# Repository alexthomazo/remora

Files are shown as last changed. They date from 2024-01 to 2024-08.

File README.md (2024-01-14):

Remora
======

Contrôleur fil pilote permettant de contrôler 7 zones et un relai.

Basé sur ESP32 et ESPHome.

Version 2.0 de Remora basé sur https://github.com/tducret/programmateur-fil-pilote-wifi/tree/master

Fonctionnalités
---------------

 * ESP32 Mini D1
 * MCP23017 pour le contrôle des 7 zones et du relai
 * Port ethernet optionnel
 * Connecteur I2C pour ecran OLED
 * Relai permettant le contrôle d'un connecteur heures pleines/creuses

Changements depuis la version 1.3
---------------------------------

 * Ajout
   - Ajout d'un condensateur 47u en entrée pour filtrage
   - Port Ethernet (optionnel)
   - Snubber RC pour maximiser la durée de vie du relai
   - LED "relai" indépendante

 * Modification
   - Base ESP32 D1 mini
   - MCP23017 en SMD pour gain de place
   - Téléinfo basée sur Denky D4 avec résistance variable et LED
   - Nouvelle ref opto fils pilotes TLP267J
   - Nouvelle ref relai G5Q-1 (mécanique moins cher SSR) 
   
 * Suppression
   - récepteurs sans fils 433 et 868Mhz
   - connecteurs SPI et Groove I2C
   - LED 3mm RGB

Les composants SMD (hors partie LAN) sont prévus pour être soudés au fer.

Schématique
-----------

Schématique

Board
-----

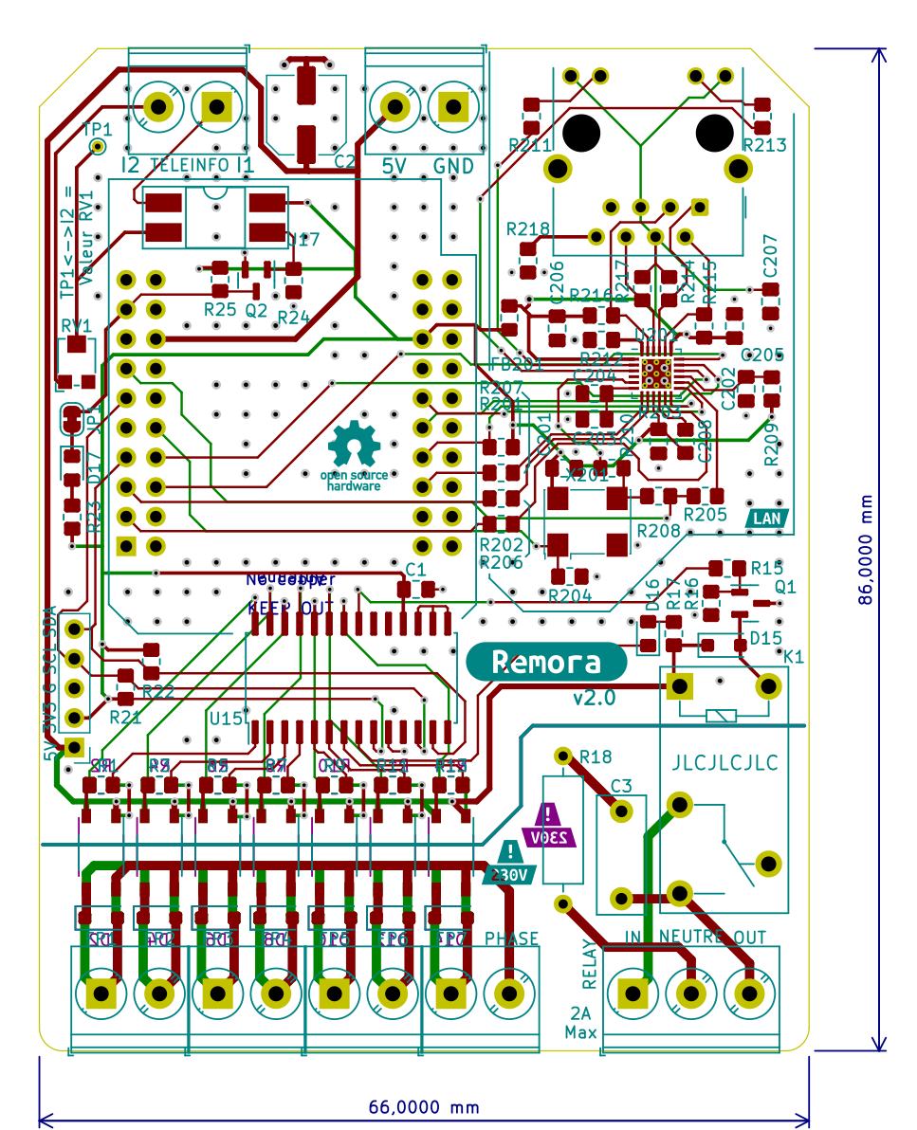
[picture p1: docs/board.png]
Board


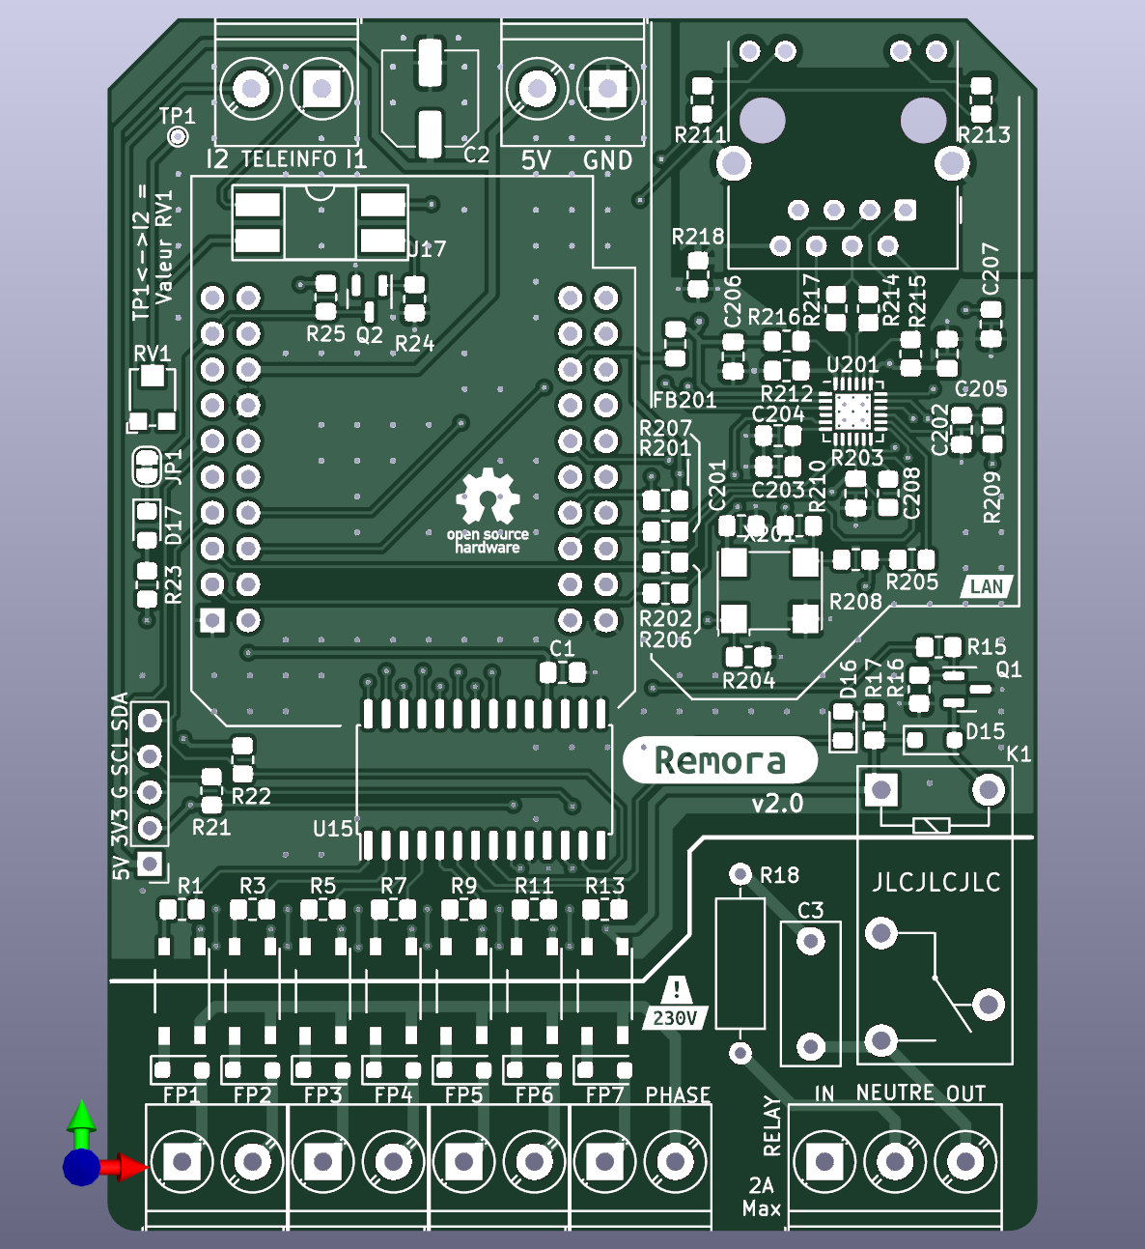
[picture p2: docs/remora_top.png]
Board top

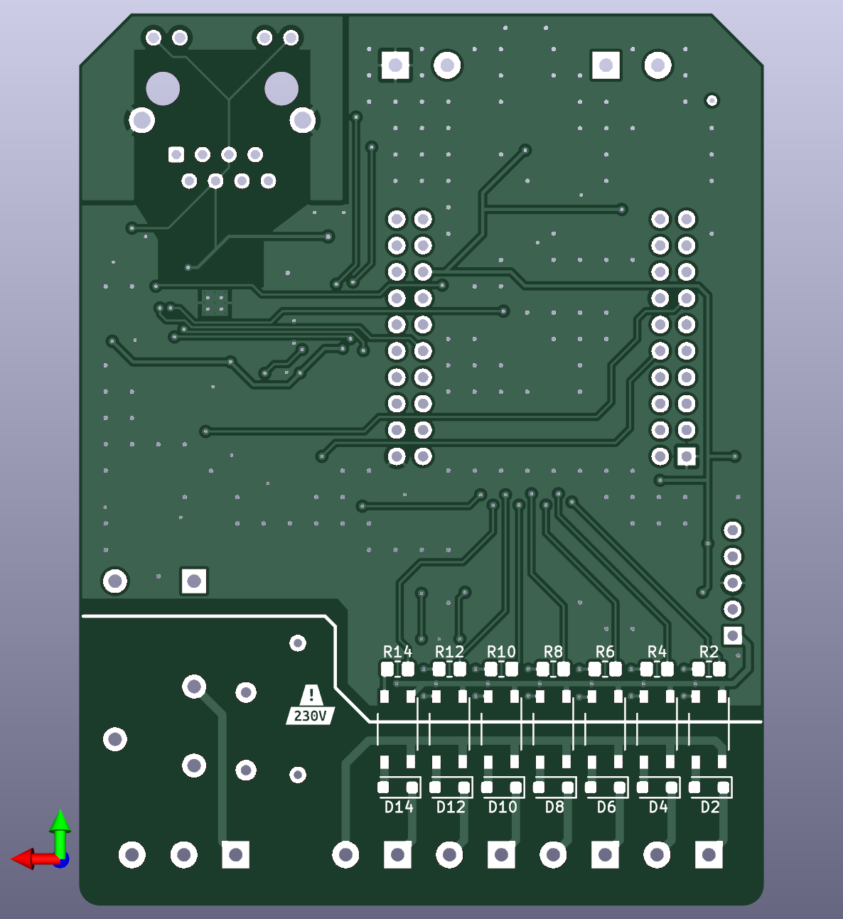
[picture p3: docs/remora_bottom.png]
Board bottom


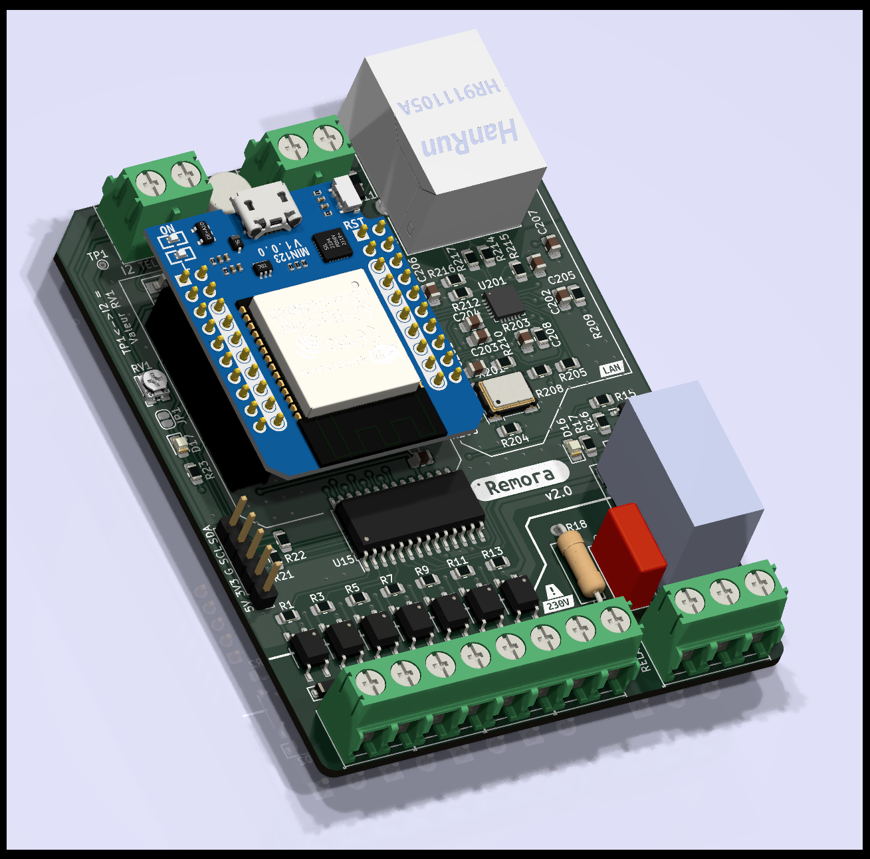
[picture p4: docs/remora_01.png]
Board 3D 01

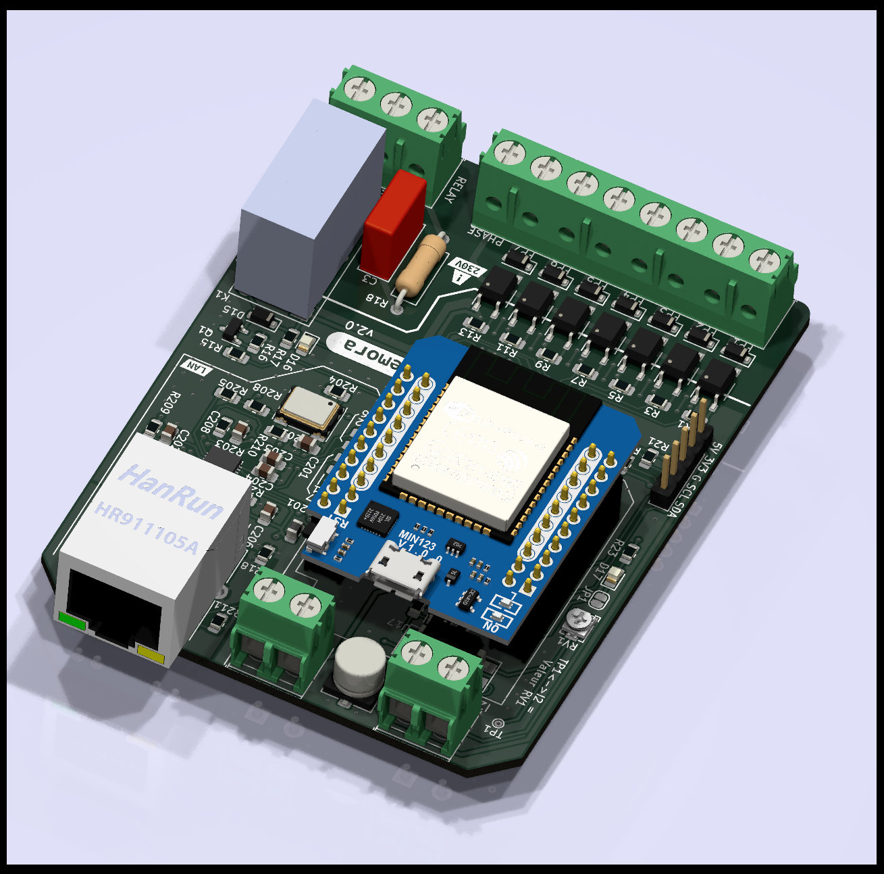
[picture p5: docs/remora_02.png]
Board 3D 02


Case
----

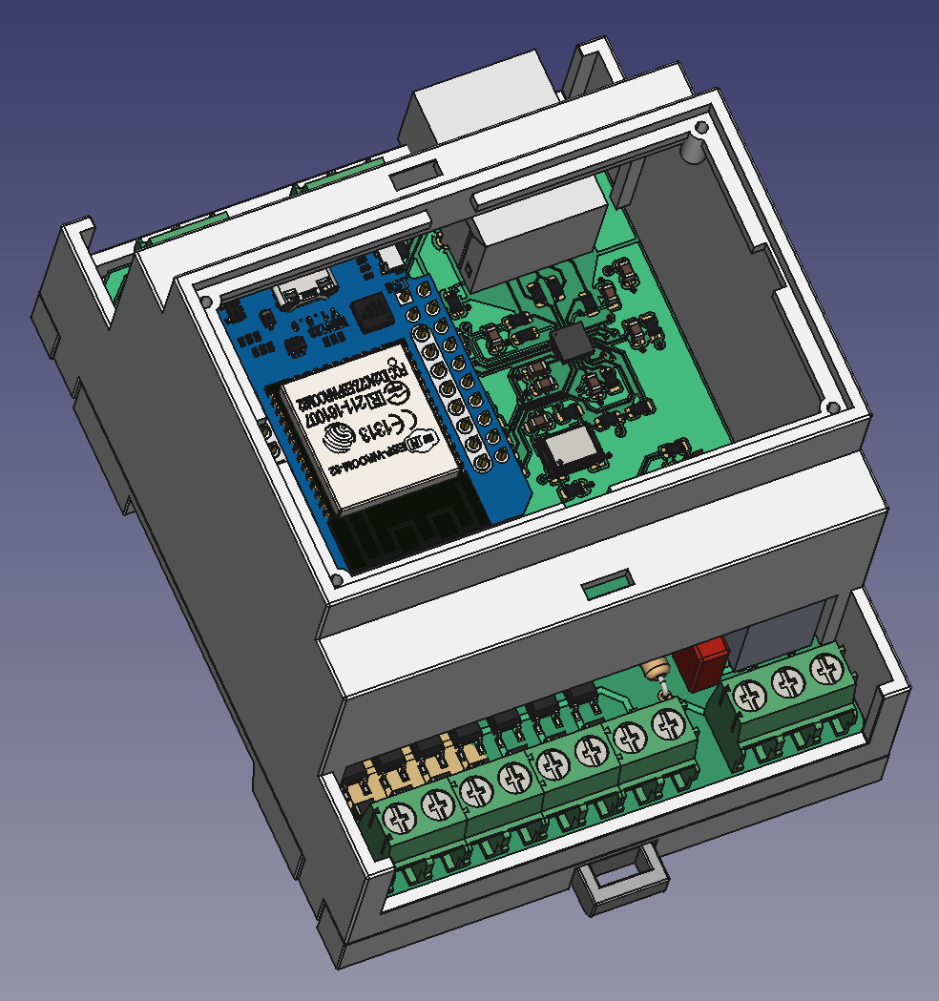
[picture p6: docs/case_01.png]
Case open

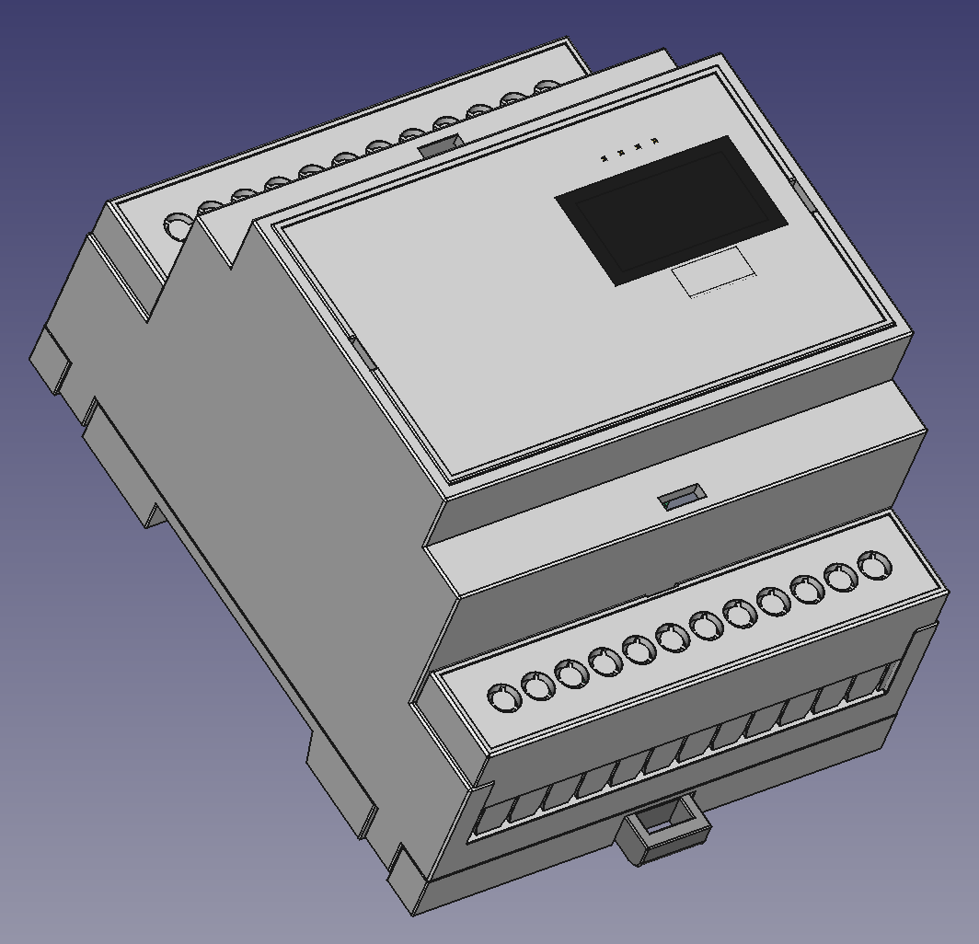
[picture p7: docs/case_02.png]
Case close with OLED


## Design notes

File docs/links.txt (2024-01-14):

Remora:
https://github.com/tducret/programmateur-fil-pilote-wifi/tree/master/Mat%C3%A9riel/1.3
https://github.com/hallard/Denky-D4

LAN:
https://www.waveshare.com/w/upload/0/08/LAN8720-ETH-Board-Schematic.pdf
https://ww1.microchip.com/downloads/en/DeviceDoc/EVB8720%20Evaluation%20Board%20Schematic.pdf
https://pcbartists.com/design/embedded/esp32-ethernet-phy-schematic-design/

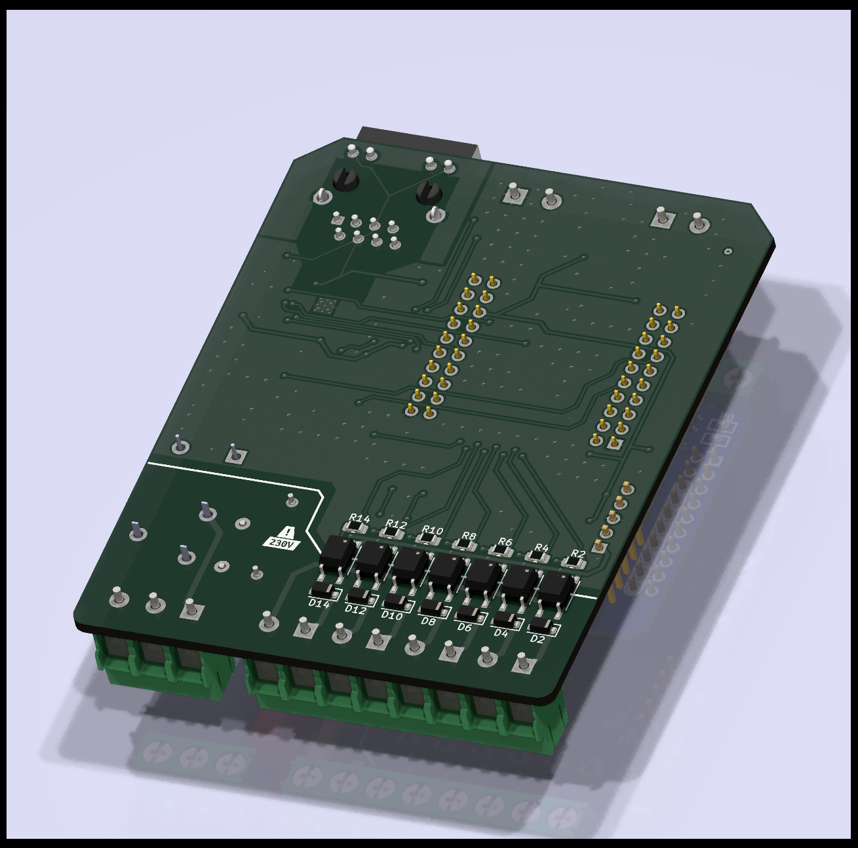
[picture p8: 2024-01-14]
docs/remora_03.png

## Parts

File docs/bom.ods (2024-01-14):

Pièce | Qte | Fabricant | Réf | P.U. | P.T.
Condo Alim | 1 |  | 47u electrolytique | 0,0326 € | 0,0326 € | https://www.mouser.fr/ProductDetail/KEMET/EDK476M035A9GAA?qs=Z46kSA%2FmtFgpOMpd%252BYN4FQ%3D%3D | https://www.lcsc.com/product-detail/Aluminum-Electrolytic-Capacitors-SMD_ROQANG-RVE1V470M0605_C131122.html
Borniers Alim | 1 |  | 2P | 0,0838 € | 0,0838 € |  | https://www.lcsc.com/product-detail/Screw-terminal_MAX-MX127-5-0-02P-GN01-Cu-Y-A_C5188440.html
MCU | 1 |  | ESP 32 Mini | 5,0000 € | 5,0000 € | https://fr.aliexpress.com/item/1005005972627549.html
Expandeur IO | 1 | Microchip | MCP23017-E/SO | 1,4386 € | 1,4386 € | https://www.mouser.fr/ProductDetail/Microchip-Technology/MCP23017-E-SO?qs=usxtMOJb1Rz8hft7vV7YMQ%3D%3D | https://www.lcsc.com/product-detail/I-O-Expanders_Microchip-Tech-MCP23017-E-SO_C47023.html
Condo Exp | 1 |  | 100 nF | 0,0043 € | 0,0043 € | https://www.mouser.fr/ProductDetail/YAGEO/CC0805KRX7R9BB104?qs=vTakOoo5QyLx0lXWgVtRhQ%3D%3D | https://www.lcsc.com/product-detail/Multilayer-Ceramic-Capacitors-MLCC-SMD-SMT_YAGEO-CC0805KRX7R9BB104_C49678.html
Resistance I2C | 2 |  | 4.7k | 0,0021 € | 0,0042 € |  | https://www.lcsc.com/product-detail/Chip-Resistor-Surface-Mount_YAGEO-RC0805FR-074K7L_C60816.html
Opto FP | 14 |  | TLP267J | 0,5218 € | 7,3052 € | https://www.mouser.fr/ProductDetail/Toshiba/TLP267JE?qs=vPP9GyyTAo3MM33pScxJbA%3D%3D | https://www.lcsc.com/product-detail/Optocouplers-Thyristor-Signal-Output_TOSHIBA-TLP267J-TPL-E-T_C393892.html
Resistance Opto | 14 |  | 680 | 0,0019 € | 0,0266 € |  | https://www.lcsc.com/product-detail/Chip-Resistor-Surface-Mount_YAGEO-RC0805FR-07680RL_C114549.html
Diode FP | 14 |  | 1N4007 | 0,0051 € | 0,0714 € | https://www.mouser.fr/ProductDetail/onsemi/NRVS1MFL?qs=%252B6g0mu59x7LVREuEHuiGKw%3D%3D | https://www.lcsc.com/product-detail/Diodes-General-Purpose_TWGMC-1N4007_C727082.html
Borniers FP | 4 |  | 2P | 0,0838 € | 0,3352 € |  | https://www.lcsc.com/product-detail/Screw-terminal_MAX-MX127-5-0-02P-GN01-Cu-Y-A_C5188440.html
Opto Tele | 1 | Lite-On | LTV-814S | 0,1049 € | 0,1049 € | https://www.mouser.fr/ProductDetail/Lite-On/LTV-814S | https://www.lcsc.com/product-detail/Optocouplers-Phototransistor-Output_Lite-On-LTV-814S-TA1_C125118.html
Resistance Opto Tele | 1 |  | Variable 0 → 2K | 0,0702 € | 0,0702 € |  | https://www.lcsc.com/product-detail/Variable-Resistors-Potentiometers_HDK-Hokuriku-Elec-Industry-VG039NCHXTB202_C128549.html
MOSFET Tele | 1 | onsemi | BSS138 | 0,0224 € | 0,0224 € | https://www.mouser.fr/ProductDetail/onsemi-Fairchild/BSS138 | https://www.lcsc.com/product-detail/MOSFETs_LGE-BSS138_C713688.html
Resistance MOSFET | 1 |  | 3K3 | 0,0024 € | 0,0024 € |  | https://www.lcsc.com/product-detail/Chip-Resistor-Surface-Mount_YAGEO-RC0805FR-073K3L_C114531.html
Resistance MOSFET | 1 |  | 10K | 0,0019 € | 0,0019 € |  | https://www.lcsc.com/product-detail/Chip-Resistor-Surface-Mount_YAGEO-RC0805JR-0710KL_C100047.html
Led Tele | 1 |  | Bleue | 0,0118 € | 0,0118 € | https://www.mouser.fr/ProductDetail/Inolux/IN-S85AT5B | https://www.lcsc.com/product-detail/Light-Emitting-Diodes-LED_Yongyu-Photoelectric-SZYY0805B_C434433.html
Resistance Led Tele | 1 |  | 470 | 0,0020 € | 0,0020 € |  | https://www.lcsc.com/product-detail/Chip-Resistor-Surface-Mount_YAGEO-RC0805FR-07470RL_C114564.html
Borniers Teleinfo | 1 |  | 2P | 0,0838 € | 0,0838 € |  | https://www.lcsc.com/product-detail/Screw-terminal_MAX-MX127-5-0-02P-GN01-Cu-Y-A_C5188440.html
Connecteur Ecran OLED | 1 |  | 1x4P | 0,0649 € | 0,0649 € |  | https://www.lcsc.com/product-detail/Female-Headers_ZHOURI-PM2-54-1-4_C5116530.html
Relai | 1 | Panasonic | ALQ105 (https://www3.panasonic.biz/ac/e_download/control/relay/power/catalog/mech_eng_lq.pdf) | 0,9281 € | 0,9281 € | https://www.mouser.fr/ProductDetail/Panasonic-Industrial-Devices/ALQ105?qs=kkkG%2F8HgOiLTrZ6QoQqhfg%3D%3D | https://www.lcsc.com/product-detail/Power-Relays_PANASONIC-ALQ105_C719517.html
Diode Relais | 1 |  | 1N4007 | 0,0051 € | 0,0051 € |  | https://www.lcsc.com/product-detail/Diodes-General-Purpose_TWGMC-1N4007_C727082.html
Transistor Relai | 1 |  | MMBT2222 | 0,0067 € | 0,0067 € |  | https://www.lcsc.com/product-detail/Bipolar-Transistors-BJT_JSMSEMI-MMBT2222A_C916372.html
Resistance Relai | 1 |  | 1k | 0,0020 € | 0,0020 € |  | https://www.lcsc.com/product-detail/Chip-Resistor-Surface-Mount_YAGEO-RC0805FR-071KL_C95781.html
Resistance Relai | 1 |  | 10k | 0,0019 € | 0,0019 € |  | https://www.lcsc.com/product-detail/Chip-Resistor-Surface-Mount_YAGEO-RC0805JR-0710KL_C100047.html
Snubber R | 1 |  | 220R / 1/2W | 0,0177 € | 0,0177 € |  | https://www.lcsc.com/product-detail/Through-Hole-Resistors_CCO-Chian-Chia-Elec-MF1-2W-220-1-T_C119410.html
Snubber C | 1 |  | 0.1uF / 600V | 0,0572 € | 0,0572 € | https://www.mouser.fr/ProductDetail/Panasonic/ECW-FD2J104K4?qs=7EBvPakHacU48DCioWGmwQ%3D%3D | https://www.lcsc.com/product-detail/Polypropylene-Film-Capacitors-CBB_SRD-Shenzhen-Sincerity-Tech-MPP104J2J1006115LC_C2895620.html
Borniers relai | 1 |  | 3P | 0,0743 € | 0,0743 € |  | https://www.lcsc.com/product-detail/Screw-terminal_MAX-MX127-5-0-03P-GN01-Cu-Y-A_C5188441.html
LED Relai | 1 |  | Rouge | 0,0086 € | 0,0086 € | https://www.mouser.fr/ProductDetail/Inolux/IN-S85AT5UW | https://www.lcsc.com/product-detail/Light-Emitting-Diodes-LED_XINGLIGHT-XL-2012VRC_C7371913.html
Ecran OLED I2C | Opt |  | SSD1306 |  |  | https://fr.aliexpress.com/item/1005004495098319.html

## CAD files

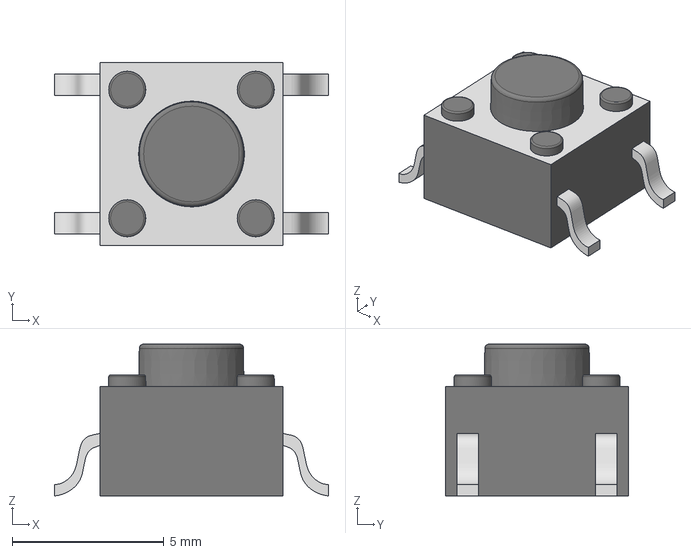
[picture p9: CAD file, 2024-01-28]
3d/Tactal Switch - SMD (6mm x 6mm x 5mm).stp
9.02 x 6.03 x 5.00 mm

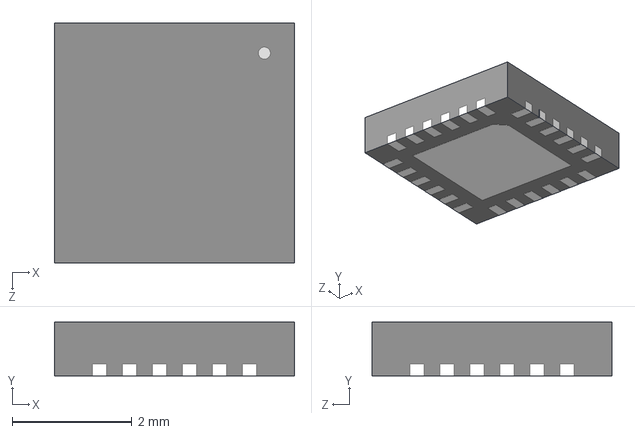
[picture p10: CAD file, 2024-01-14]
3d/QFN 24 4x4.step
4.00 x 0.9 x 4.00 mm

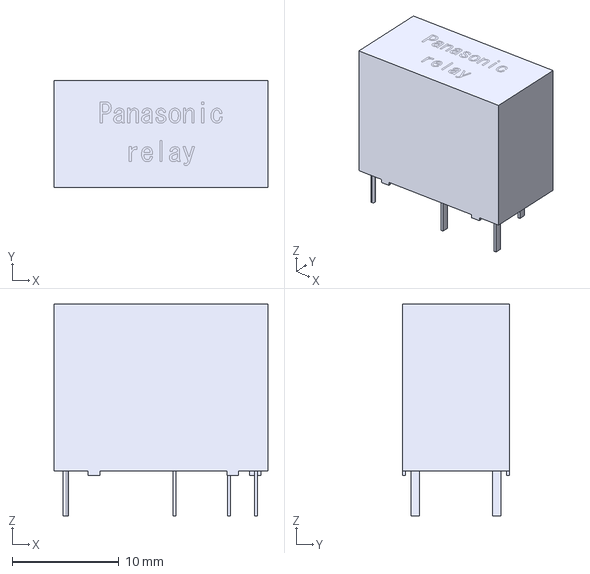
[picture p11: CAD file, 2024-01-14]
3d/alq1.step
20.0 x 10.0 x 19.8 mm

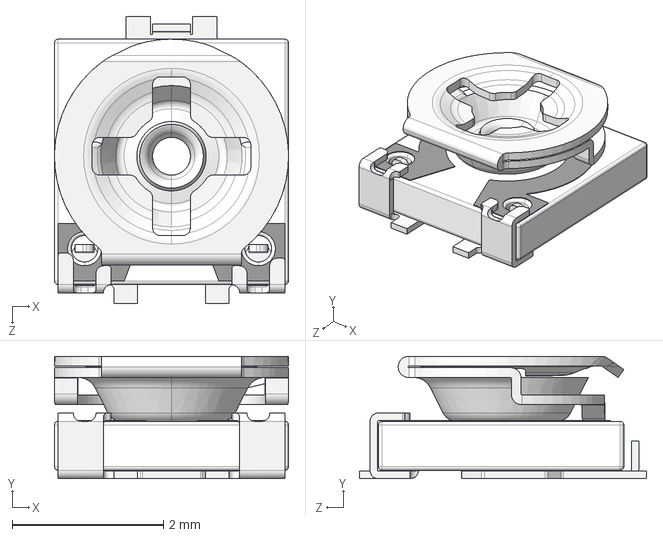
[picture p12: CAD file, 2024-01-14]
3d/EVM3ESX50Bxx-Panasonic.STEP
3.10 x 1.62 x 3.80 mm

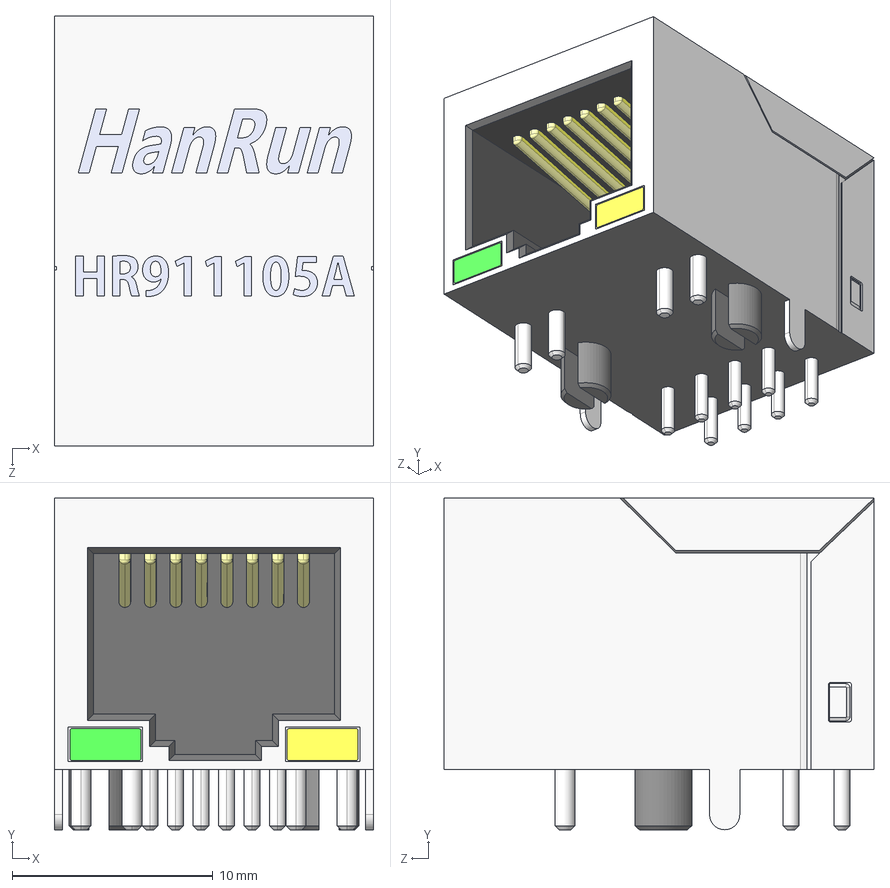
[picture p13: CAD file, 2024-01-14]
3d/HR911105A.STEP
15.9 x 16.5 x 21.4 mm

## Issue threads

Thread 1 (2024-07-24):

TELEINFO PIN

baramuse, 2024-07-24:
Hi,

I've got a question conerning the pinout: if I undestrand correctly, the TELEINFO info pin is mapped to SD1/GPIO8 on ESP32 ?
If so, is that correct as the ESP32 doc states the SD1 is reserved :
`This pin cannot be used on ESP32s and is already used by the flash interface (function: Flash Data 1).`

Any clue ?

alexandre-thomazo-idnow, 2024-07-24:
Hello,

Yes, I just test it last week and realized the issue, I pushed a new version with the pin routed to GPIO13 and made a hardware patch with a strap wire. It's working with this pin :)

alexthomazo, 2024-07-24:
Hello,

Yes, I just test it last week and realized the issue, I pushed a new version with the pin routed to GPIO13 and made a hardware patch with a strap wire. It's working with this pin :)

baramuse, 2024-07-24:
damned I've printed a few pcb already :')

baramuse, 2024-07-24:
> Hello,
>
> Yes, I just test it last week and realized the issue, I pushed a new version with the pin routed to GPIO13 and made a hardware patch with a strap wire. It's working with this pin :)

could you share a picture of your hardware patch ?

alexthomazo, 2024-07-24:
Erf, I don't have a picture right now but the hardware patch is not to complicated. I cut the trace that going left of the R25 resistor with a cutter.
Then I take a strap wire, solder on the bottom pad of the resistor the routing it on the bottom layer going right of the power pin then solder it to the ESP32 pin of the GPIO13.

Here's a quick draw on the PCB of the wire
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

baramuse, 2024-07-24:
Alright !
Do you think I could do the hardware patch on the wemo instead ?
Cut the trace of the GPIO8 -> ESP and strap wire GPIO8->GPIO13 ?
I'd rather mess a 4$ board that the remora2 ^^

alexthomazo, 2024-07-24:
Yes I can think so, you cut the trace just after the pad and redirect with a wire at the other pin like that
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

baramuse, 2024-07-25:
Well I did the hardware patch.
Tested the continuity bewteen GPIO8 and GPIO16 (green wire on your schematics) and the non-continuity between GPIO8 and the 3rd vertical pad on the CPU (SD1) but when powerd, nothing get to the TELEINFO.
The blue led is not blinking. It actually WAS blinking before the hardware patch - but then I guess just because SD1 was live..)
Any idea how to "debug" that ?

By the way, are you programming with ESPHome ?

Cheers

alexthomazo, 2024-07-25:
That's weird, for me as soon as I put the the teleinfo on the right pin, it was working right away. However I cut the trace for the led before (it was also blinking when connected to SD1, I supposed at the moment that it was triggered because the teleinfo was not connected at all).
I don't really know how to debug, I use ESPHome indeed, I was planning to upload an configuration example in the following days but I can push it right know if you want to check with yours.

alexthomazo, 2024-07-25:
I push my [ESPHome configuration](https://github.com/alexthomazo/remora/blob/main/esphome/esphome.yaml), I'm in standard mode however.

Maybe it came from the uart configuration, because the ESP32 has 2 uart (that's why it's id uart_1 if I remember correctly).

baramuse, 2024-07-25:
Yep, same thing but I called it `uart_bus` instead of `uart_1` in your case but samed same.

baramuse, 2024-07-25:
Well.. I thought I misolder the opto, but I tried twice and still nothing and I don't know how to "debug" :(

alexthomazo, 2024-07-25:
ok, I think you don't have a logic analyzer or an oscilloscope to check if you have a signal a the output of the optocoupler or the mosfet ^^ ?

baramuse, 2024-07-25:
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

baramuse, 2024-07-25:
sadly not yet, but I'll end up buying one I guess

baramuse, 2024-07-25:
humm I do have continuity between I1 -> TI1 (on the opto) but not from I2 -> TI2R
I do have continuity between I1 -> TP1 though... what's the RV1 thingy ?

alexthomazo, 2024-07-25:
That's so cool to see the project build by someone else :grin:

RV1 is a variable resistor to adjust the signal coming from the counter, if you don't already play with check, try to turn to see if it's better or not.

baramuse, 2024-07-25:
turning it left gives me continuity I2 -> TI2R.
should I tune it to a more specific value ?
still no teleinfo though.

alexthomazo, 2024-07-25:
I'm not an expert on that topic, maybe asking in the Remora forum to have more users with knowledge of the historique mode of the teleinfo ?

baramuse, 2024-07-25:
I don't think historical or standard have an impact on my issue here :)
RV1 is a variable resistor then ? it means I need to set it to a particular value ?

reading charle's blog, especially on "choix des resistances" I feel i need to get it to around 4.7k
also in his designs he puts a 4,7K on I2 ? https://github.com/hallard/teleinfo/tree/master/MicroTeleinfo

baramuse, 2024-07-25:
Turning it all the way to the right gives me a 2.14K, is it the highest value ?

alexthomazo, 2024-07-25:
> Turning it all the way to the right gives me a 2.14K, is it the highest value ?

Yes, it's a 2K variable resistor, I take the specs from the Denky D4 for that part https://github.com/hallard/Denky-D4

baramuse, 2024-07-25:
yep, makes sense... well I don't know what's wrong with my teleinfo then :(
so close yet so far !

alexthomazo, 2024-07-25:
it was working before with the same cable on the old remora ?

baramuse, 2024-07-25:
not a remora but a wemosD1 with a shield (and still works when I plug it back in)

baramuse, 2024-07-25:
I should see the blue led blink whenever I have any teleinfo right ? (ruling out the software component)

alexthomazo, 2024-07-25:
Yes, the led is connected to the mosfet so it should blink without any software

baramuse, 2024-07-25:
ok something must be wrong with my opto (the only component that did not come soldered ^^) because I got no blue led when only powered (no ESP32).
I tried swaping the teleinfo wires, etc, nothing... so must be my opto

alexthomazo, 2024-07-25:
> ok something must be wrong with my opto (the only component that did not come soldered ^^) because I got no blue led when only powered (no ESP32). I tried swaping the teleinfo wires, etc, nothing... so must be my opto

You need to at least have the ESP32 plugged in because it's provide the 3.3V required for the opto, if you want to test without nothing, link at least the 3.3V of the ESP to the board with jump wires.

baramuse, 2024-07-25:
Alright I tried again, plugged the old Wemos nd worked, so must be something with the opto (I recycled it from another pitinfo...)
I'll order the wright ones and try again !
Thanks for the support !

baramuse, 2024-10-09:
> ![image](https://private-user-images.githubusercontent.com/1180901/352177930-d5ff3795-6b68-4608-a7d7-b4667a161c73.jpeg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) ![image](https://private-user-images.githubusercontent.com/1180901/352178087-fe93ba37-66a8-4edb-9809-cf10a06de4cf.jpeg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)
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
baramuse, 2024-10-12:
Thanks !
Just ordered them..
I'll try the hw hack for the relay later.
So that's the second hw update with the reassign of GPIO13 right ?
Also, can't the snubber be implemented on the board as well ?
And in your changelog you actually already said `Snubber RC pour maximiser la durée de vie du relai` ?

How hard would it e to replace the ETHERNET circuitery with a 220V/5V transformer ?
As you already have a 220V input (and output if you use the relay) that would remove the need of another device to get the 5volts

Also, you already have the PHASE input for the FPs, couldn't you merge it with the IN of the relay in order to only tu plug one in ? (they maybe are stupid questions, I'm not electronician, but more a cable hunter ^^)

alexthomazo, 2024-10-12:
> So that's the second hw update with the reassign of GPIO13 right ?

Yes, and also the last one, I have the board running with these two updates for several weeks now and it's working well.

> Also, can't the snubber be implemented on the board as well ? And in your changelog you actually already said `Snubber RC pour maximiser la durée de vie du relai` ?

I didn't included the snubber directly with the relay on the PCB traces so you can use the relay for other thing if you want (like controlling a light), the snubber is only needed because the small relay of the PCB is going to drive the bigger relay of the hotwater. The drawback is that you must to do the connection at the outside.

> How hard would it e to replace the ETHERNET circuitery with a 220V/5V transformer ? As you already have a 220V input (and output if you use the relay) that would remove the need of another device to get the 5volts And maybe lower the overall price if no ethernet is needed

I also thought about it, but first I wanted to have Ethernet, and secondly, I'm not a 100% confident with 220V current, so I kept the remora original design that kept all the high current at the bottom of the PCB. However it will be completely doable to rework the right part, removing the Ethernet then put a integrated transformer.

> Also, you already have the `PHASE` input for the `FPx`, couldn't you merge it with the `IN` of the relay in order to only tu plug one in ?

For the same reason of not including the snubber directly, I did not include the `PHASE` with the relay so you can use it to do whatever you want (and also drive something from another circuit breaker).

> (they maybe are stupid questions, I'm not electronician, but more a cable hunter ^^)

Not stupid at all, as you can see I think about that and made some choices, it's cool to see someone interested with the project and trying to understand :)

alexandre-thomazo-idnow, 2024-10-28:
> it looks on my printed board, I already had that fix, right ?

Oh yes, you should had made the PCB printed after I made the fix, good for you

> Also I plan to put that RC snubber in parrallel is that right ?

Yes, it's the right thing :)

baramuse, 2024-10-30:
Alright !
It starts working !

I've set it up with my HA installation and it starts talking with the heaters !!

Have you tested all the modes ?
On my side, at least for now, the heater "understands" correcly the "off" and "hors-gel" instructions. (both "half signals")
It seems unresponsive to "eco" and "confort" (both "full signals")

Not sure how can I test what's wrong.
I've bought a handeled oscilloscope (BSIDE ZT-702S) but I'm not sure I understand what I'm seeing...

Any clues ?

Cheers

alexthomazo, 2024-10-31:
Hello, yes, all the modes are working on my side.

That's odd that you have only "half" signal working, because in order to have "full" signal, it's just a combinaison of the 2 "half" signal.

Are you sure that the configuration in HA is OK ? You need to activate 2 pins on the MCP to have the "full" signal.

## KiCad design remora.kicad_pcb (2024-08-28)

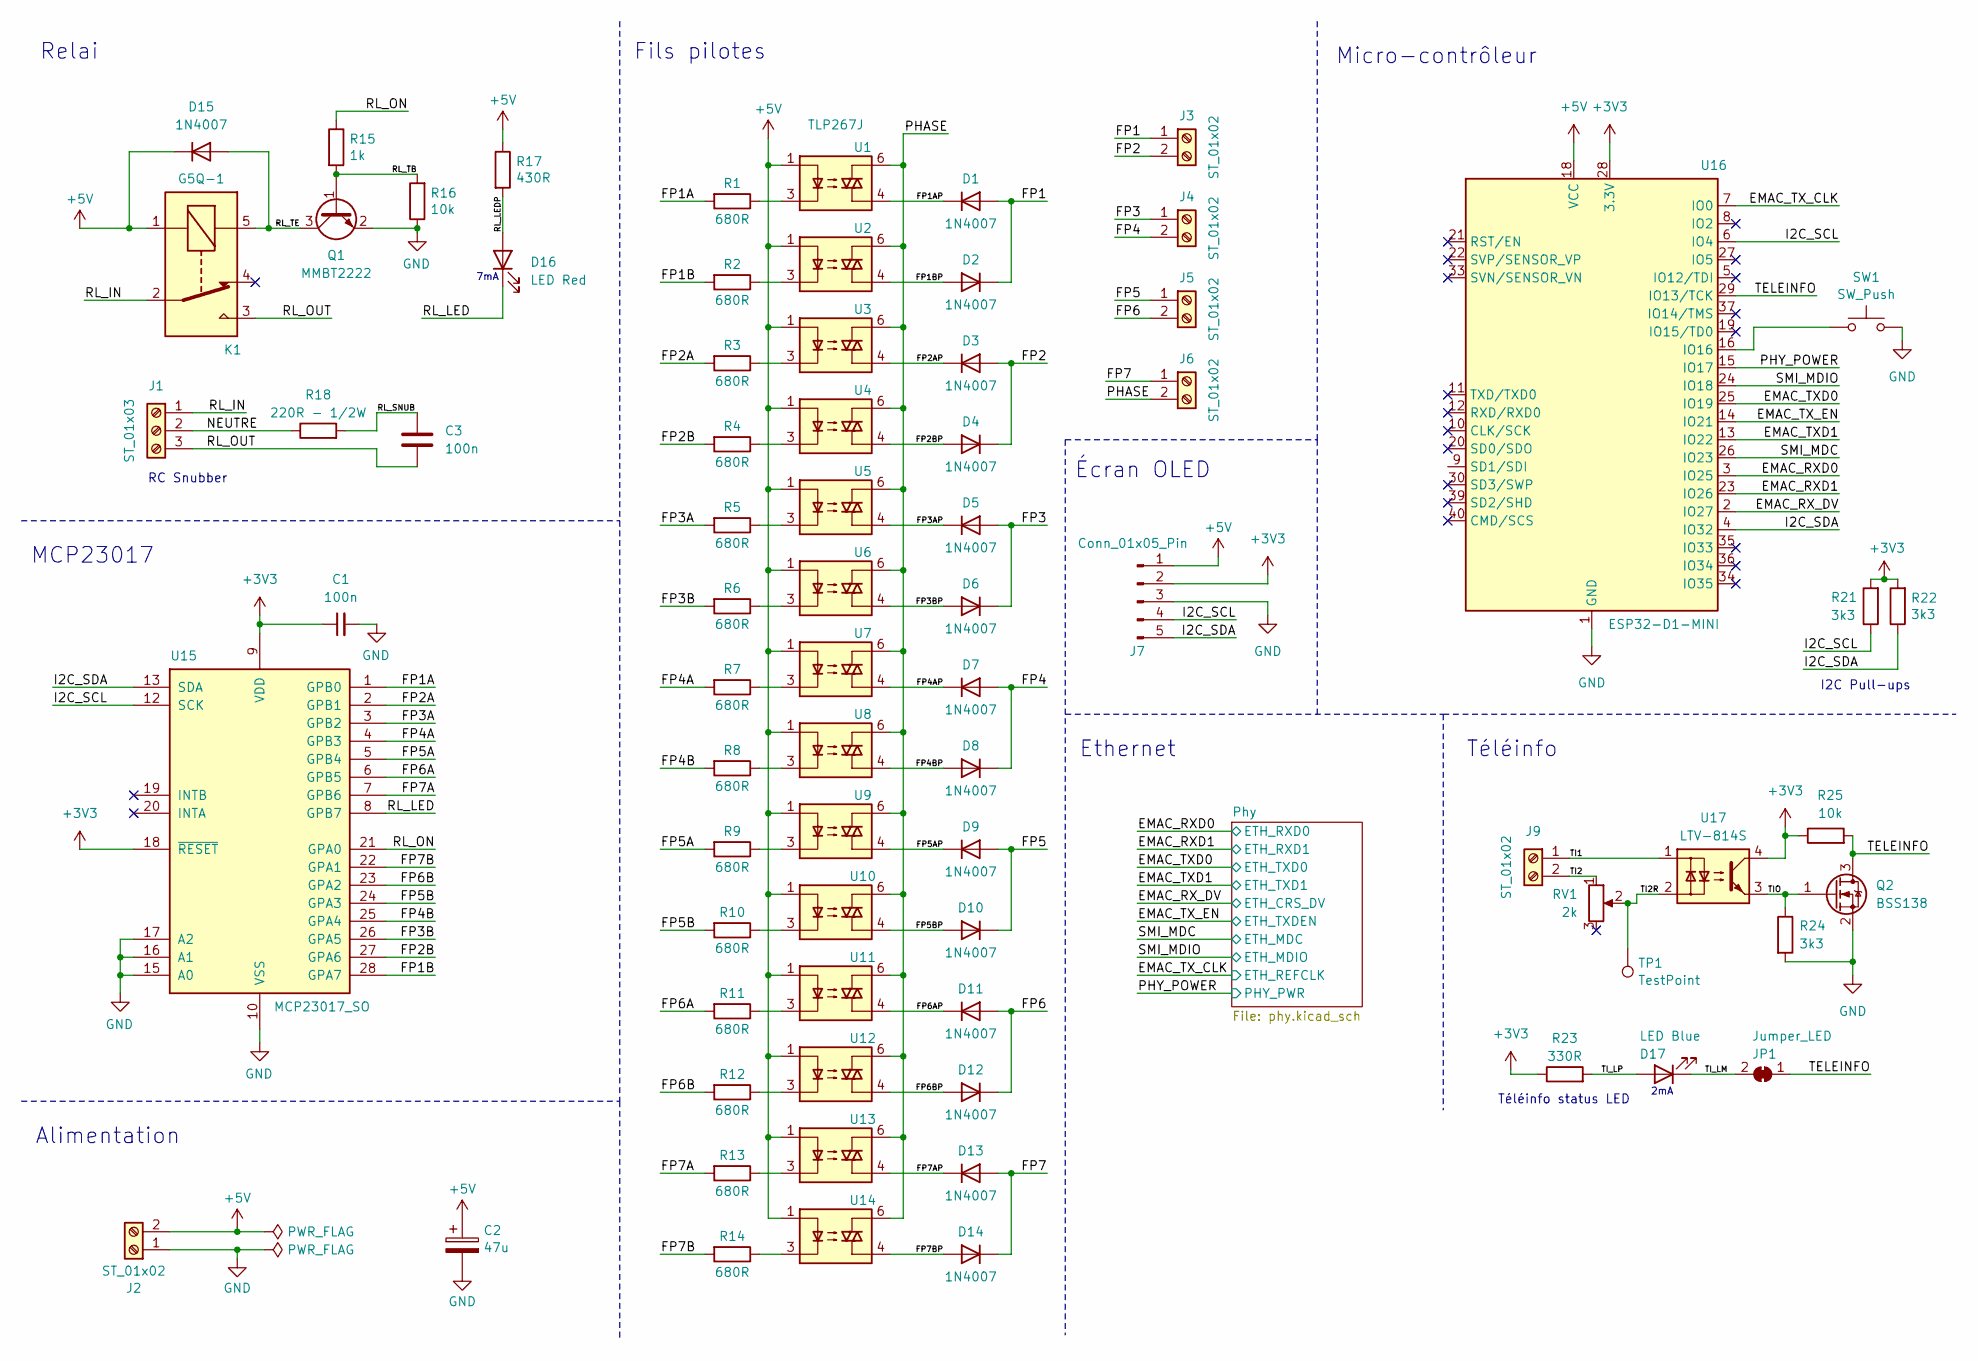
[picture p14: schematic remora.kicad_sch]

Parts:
C1: 100n; C_0805_2012Metric_Pad1.18x1.45mm_HandSolder; Mouser# 603-CC805KRX7R9BB104; LCSC# C49678
C2: 47u; C_Elec_6.3x5.4; Mouser# 80-EDK476M035A9GAA; LCSC# C131122
C3: 100n; C_Rect_L11.5mm_W5.6mm_P10.00mm_MKT; LCSC# C506867
D1, D2, D3, D4, D5, D6, D7, D8, D9, D10, D11, D12, D13, D14, D15: 1N4007; D_SOD-123FL; Mouser# 863-NRVS1MFL; LCSC# C727082
D16: LED Red; LED_0805_2012Metric_Pad1.15x1.40mm_HandSolder; Mouser# 743-IN-S85AT5UW; LCSC# C7371913
D17: LED Blue; LED_0805_2012Metric_Pad1.15x1.40mm_HandSolder; Mouser# 743-IN-S85AT5B; LCSC# C434433
J1: ST_01x03; TerminalBlock_Phoenix_PT-1,5-3-5.0-H_1x03_P5.00mm_Horizontal; Mouser# 490-TB003-500-P03BE; LCSC# C5188464
J2, J3, J4, J5, J6, J9: ST_01x02; TerminalBlock_Phoenix_PT-1,5-2-5.0-H_1x02_P5.00mm_Horizontal; Mouser# 490-TB003-500-P02BE; LCSC# C5188463
J7: Conn_01x05_Pin; PinHeader_1x05_P2.54mm_Vertical; Mouser# 200-EW0509TS300; LCSC# C492404
JP1: Jumper_LED; SolderJumper-2_P1.3mm_Bridged_RoundedPad1.0x1.5mm
K1: G5Q-1; Relay_SPDT_Omron-G5Q-1; Mouser# 769-ALQ105; LCSC# C719517
Q1: MMBT2222; SOT-23; Mouser# 771-MMBT2222A215; LCSC# C916372
Q2: BSS138; SOT-23; Mouser# 771-BSS138P215; LCSC# C713688
R1, R2, R3, R4, R5, R6, R7, R8, R9, R10, R11, R12, R13, R14: 680R; R_0805_2012Metric_Pad1.20x1.40mm_HandSolder; Mouser# 603-RC0805FR-07680RL; LCSC# C114549
R15: 1k; R_0805_2012Metric_Pad1.20x1.40mm_HandSolder; Mouser# 603-RC0805FR-071KL
R16, R25: 10k; R_0805_2012Metric_Pad1.20x1.40mm_HandSolder; Mouser# 603-RC0805FR-0710KL
R17: 430R; R_0805_2012Metric_Pad1.20x1.40mm_HandSolder; Mouser# 603-RC0805FR-07430RL
R18: 220R - 1/2W; R_Axial_DIN0309_L9.0mm_D3.2mm_P12.70mm_Horizontal; Mouser# 603-CFR-50JR-52-220R; LCSC# C119410
R21, R22, R24: 3k3; R_0805_2012Metric_Pad1.20x1.40mm_HandSolder; Mouser# 603-RC0805FR-073K3L
R23: 330R; R_0805_2012Metric_Pad1.20x1.40mm_HandSolder; Mouser# 603-RC0805FR-07330RL; LCSC# C105878
RV1: 2k; Potentiometer_Bourns_TC33X_Vertical; Mouser# 652-TC33X-2-202E; LCSC# C128549
SW1: SW_Push; SW_Push_1P1T_NO_6x6mm_H9.5mm; Mouser# 179-TS046655BK160SMT; LCSC# C255812
TP1: TestPoint; TestPoint_THTPad_D1.0mm_Drill0.5mm
U1, U2, U3, U4, U5, U6, U7, U8, U9, U10, U11, U12, U13, U14: TLP267J; MFSOP6-4_4.4x3.6mm_P1.27mm; Mouser# 757-TLP267JE; LCSC# C393892
U15: MCP23017_SO; SOIC-28W_7.5x17.9mm_P1.27mm; Mouser# 579-MCP23017-E/SO; LCSC# C629440
U16: ESP32-D1-MINI
U17: LTV-814S; DIP-4_W8.89mm_SMDSocket_LongPads; Mouser# 859-LTV-814S; LCSC# C125118

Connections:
+3V3: C1.1, J7.2, R21.2, R22.2, R23.1, R25.1, U15.9 (VDD), U15.18 (~RESET), U16.28 (3.3V), U17.4; also elsewhere on the board
+5V: C2.1, D15.1 (K), J2.2, J7.1, K1.1, R17.1, U1.1, U2.1, U3.1, U4.1, U5.1, U6.1, U7.1, U8.1, U9.1, U10.1, U11.1, U12.1, U13.1, U14.1, U16.18 (VCC)
/EMAC_RXD0: U16.3 (IO25); also elsewhere on the board
/EMAC_RXD1: U16.23 (IO26); also elsewhere on the board
/EMAC_RX_DV: U16.2 (IO27); also elsewhere on the board
/EMAC_TXD0: U16.25 (IO19); also elsewhere on the board
/EMAC_TXD1: U16.13 (IO22); also elsewhere on the board
/EMAC_TX_CLK: U16.7 (IO0); also elsewhere on the board
/EMAC_TX_EN: U16.14 (IO21); also elsewhere on the board
/FP1: D1.2 (A), D2.1 (K), J3.1
/FP1A: R1.2, U15.1 (GPB0)
/FP1AP: D1.1 (K), U1.4
/FP1B: R2.2, U15.28 (GPA7)
/FP1BP: D2.2 (A), U2.4
/FP2: D3.2 (A), D4.1 (K), J3.2
/FP2A: R3.2, U15.2 (GPB1)
/FP2AP: D3.1 (K), U3.4
/FP2B: R4.2, U15.27 (GPA6)
/FP2BP: D4.2 (A), U4.4
/FP3: D5.2 (A), D6.1 (K), J4.1
/FP3A: R5.2, U15.3 (GPB2)
/FP3AP: D5.1 (K), U5.4
/FP3B: R6.2, U15.26 (GPA5)
/FP3BP: D6.2 (A), U6.4
/FP4: D7.2 (A), D8.1 (K), J4.2
/FP4A: R7.2, U15.4 (GPB3)
/FP4AP: D7.1 (K), U7.4
/FP4B: R8.2, U15.25 (GPA4)
/FP4BP: D8.2 (A), U8.4
/FP5: D9.2 (A), D10.1 (K), J5.1
/FP5A: R9.2, U15.5 (GPB4)
/FP5AP: D9.1 (K), U9.4
/FP5B: R10.2, U15.24 (GPA3)
/FP5BP: D10.2 (A), U10.4
/FP6: D11.2 (A), D12.1 (K), J5.2
/FP6A: R11.2, U15.6 (GPB5)
/FP6AP: D11.1 (K), U11.4
/FP6B: R12.2, U15.23 (GPA2)
/FP6BP: D12.2 (A), U12.4
/FP7: D13.2 (A), D14.1 (K), J6.1
/FP7A: R13.2, U15.7 (GPB6)
/FP7AP: D13.1 (K), U13.4
/FP7B: R14.2, U15.22 (GPA1)
/FP7BP: D14.2 (A), U14.4
/I2C_SCL: J7.4, R21.1, U15.12 (SCK), U16.6 (IO4)
/I2C_SDA: J7.5, R22.1, U15.13 (SDA), U16.4 (IO32)
/NEUTRE: J1.2, R18.1
/PHASE: J6.2, U1.6, U2.6, U3.6, U4.6, U5.6, U6.6, U7.6, U8.6, U9.6, U10.6, U11.6, U12.6, U13.6, U14.6
/PHY_POWER: U16.15 (IO17); also elsewhere on the board
/RL_IN: J1.1, K1.2
/RL_LED: D16.1 (K), U15.8 (GPB7)
/RL_LEDP: D16.2 (A), R17.2
/RL_ON: R15.1, U15.21 (GPA0)
/RL_OUT: C3.1, J1.3, K1.3
/RL_SNUB: C3.2, R18.2
/RL_TB: Q1.1 (B), R15.2, R16.2
/RL_TE: D15.2 (A), K1.5, Q1.3 (C)
/SMI_MDC: U16.26 (IO23); also elsewhere on the board
/SMI_MDIO: U16.24 (IO18); also elsewhere on the board
/TELEINFO: JP1.1 (A), Q2.3 (D), R25.2, U16.29 (IO13/TCK)
/TI1: J9.1, U17.1
/TI2: J9.2, RV1.1
/TI2R: RV1.2, TP1.1, U17.2
/TIO: Q2.1 (G), R24.1, U17.3
/TI_LM: D17.1 (K), JP1.2 (B)
/TI_LP: D17.2 (A), R23.2
GND: C1.2, C2.2, J2.1, J7.3, Q1.2 (E), Q2.2 (S), R16.1, R24.2, SW1.2, U15.10 (VSS), U15.15 (A0), U15.16 (A1), U15.17 (A2), U16.1 (GND), U16.17 (GND), U16.31 (GND); also elsewhere on the board
unnamed: R1.1, U1.3
unnamed: R2.1, U2.3
unnamed: R3.1, U3.3
unnamed: R4.1, U4.3
unnamed: R5.1, U5.3
unnamed: R6.1, U6.3
unnamed: R7.1, U7.3
unnamed: R8.1, U8.3
unnamed: R9.1, U9.3
unnamed: R10.1, U10.3
unnamed: R11.1, U11.3
unnamed: R12.1, U12.3
unnamed: R13.1, U13.3
unnamed: R14.1, U14.3
unnamed: SW1.1, U16.16 (IO16)

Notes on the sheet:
7mA
MCP23017
Relai
2mA
Écran OLED
Fils pilotes
Alimentation
RC Snubber
Téléinfo
I2C Pull-ups
Ethernet
Téléinfo status LED
Micro-contrôleur

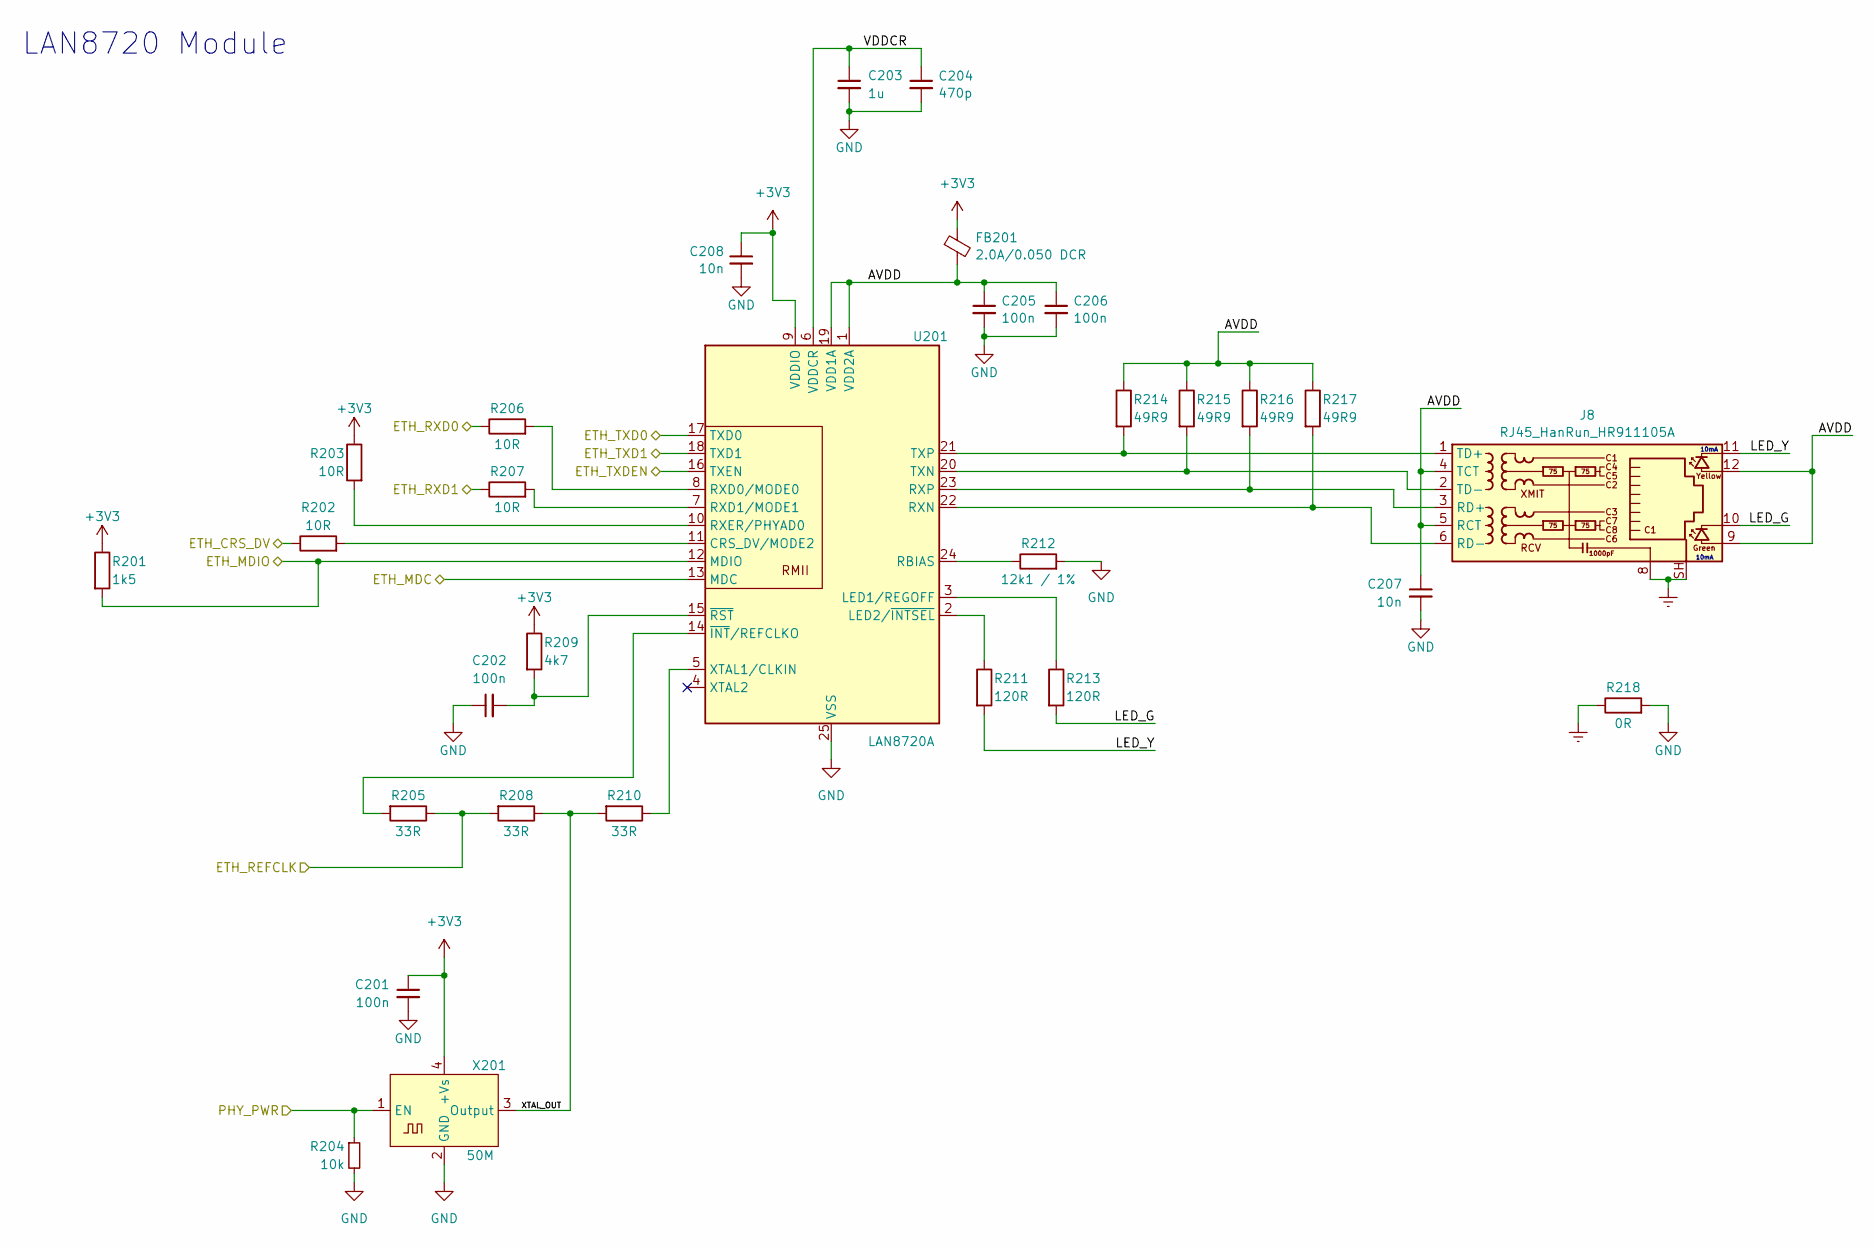
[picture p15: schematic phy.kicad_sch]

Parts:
C201, C202, C205, C206: 100n; C_0805_2012Metric_Pad1.18x1.45mm_HandSolder; Mouser# 603-CC805KRX7R9BB104; LCSC# C49678
C203: 1u; C_0805_2012Metric_Pad1.18x1.45mm_HandSolder; Mouser# 603-CC805KKX7R9BB105; LCSC# C91185
C204: 470p; C_0805_2012Metric_Pad1.18x1.45mm_HandSolder; Mouser# 603-CC805KRX7R9BB471; LCSC# C107152
C207, C208: 10n; C_0805_2012Metric_Pad1.18x1.45mm_HandSolder; Mouser# 603-CC805KRX7R9BB103; LCSC# C83170
FB201: 2.0A/0.050 DCR; L_0805_2012Metric_Pad1.15x1.40mm_HandSolder; Mouser# 81-BLM21SN300SN1D; LCSC# C596496
J8: RJ45_HanRun_HR911105A; RJ45_Hanrun_HR911105A_Horizontal; LCSC# C12074
R201: 1k5; R_0805_2012Metric_Pad1.20x1.40mm_HandSolder; Mouser# 603-RC0805FR-071K5L; LCSC# C114555
R202, R203, R206, R207: 10R; R_0805_2012Metric_Pad1.20x1.40mm_HandSolder; Mouser# 603-RC0805FR-0710RL; LCSC# C96347
R204: 10k; R_0805_2012Metric_Pad1.20x1.40mm_HandSolder; Mouser# 603-RC0805FR-0710KL
R205, R208, R210: 33R; R_0805_2012Metric_Pad1.20x1.40mm_HandSolder; Mouser# 603-RC0805FR-0733RL; LCSC# C126353
R209: 4k7; R_0805_2012Metric_Pad1.20x1.40mm_HandSolder; Mouser# 603-RC0805FR-074K7L; LCSC# C60816
R211, R213: 120R; R_0805_2012Metric_Pad1.20x1.40mm_HandSolder; Mouser# 603-RC0805FR-07120RL; LCSC# C114245
R212: 12k1 / 1%; R_0805_2012Metric_Pad1.20x1.40mm_HandSolder; Mouser# 603-RC0805FR-0712K1L; LCSC# C2933295
R214, R215, R216, R217: 49R9; R_0805_2012Metric_Pad1.20x1.40mm_HandSolder; Mouser# 603-RC0805FR-0749R9L; LCSC# C132320
R218: 0R; R_0805_2012Metric_Pad1.20x1.40mm_HandSolder; Mouser# 603-RC0805FR-070RL; LCSC# C96345
U201: LAN8720A; VQFN-24-1EP_4x4mm_P0.5mm_EP2.5x2.5mm; Mouser# 886-LAN8720A-CP-TR; LCSC# C45223
X201: 50M; Oscillator_SMD_Abracon_ASV-4Pin_7.0x5.1mm; Mouser# 815-ASV-50.000M-E-T; LCSC# C242207

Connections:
+3V3: C201.1, C208.1, FB201.1, R201.1, R203.1, R209.1, U201.9 (VDDIO), X201.4 (+Vs); also elsewhere on the board
/EMAC_RXD0: R206.1; also elsewhere on the board
/EMAC_RXD1: R207.1; also elsewhere on the board
/EMAC_RX_DV: R202.1; also elsewhere on the board
/EMAC_TXD0: U201.17 (TXD0); also elsewhere on the board
/EMAC_TXD1: U201.18 (TXD1); also elsewhere on the board
/EMAC_TX_CLK: R205.1, R208.2; also elsewhere on the board
/EMAC_TX_EN: U201.16 (TXEN); also elsewhere on the board
/PHY_POWER: R204.1, X201.1 (EN); also elsewhere on the board
/Phy/AVDD: C205.1, C206.1, C207.1, FB201.2, J8.4 (TCT), J8.5 (RCT), J8.9, J8.12, R214.1, R215.1, R216.1, R217.1, U201.1 (VDD2A), U201.19 (VDD1A)
/Phy/LED_G: J8.10, R213.2
/Phy/LED_Y: J8.11, R211.2
/Phy/VDDCR: C203.1, C204.1, U201.6 (VDDCR)
/Phy/XTAL_OUT: R208.1, R210.2, X201.3 (Output)
/SMI_MDC: U201.13 (MDC); also elsewhere on the board
/SMI_MDIO: R201.2, U201.12 (MDIO); also elsewhere on the board
Earth: J8.8, J8.SH, R218.1
GND: C201.2, C202.1, C203.2, C204.2, C205.2, C206.2, C207.2, C208.2, R204.2, R212.2, R218.2, U201.25 (VSS), X201.2 (GND); also elsewhere on the board
unnamed: J8.3 (RD+), R216.2, U201.23 (RXP)
unnamed: J8.6 (RD-), R217.2, U201.22 (RXN)
unnamed: J8.1 (TD+), R214.2, U201.21 (TXP)
unnamed: J8.2 (TD-), R215.2, U201.20 (TXN)
unnamed: R202.2, U201.11 (CRS_DV/MODE2)
unnamed: R213.1, U201.3 (LED1/REGOFF)
unnamed: R211.1, U201.2 (LED2/~INTSEL)
unnamed: R212.1, U201.24 (RBIAS)
unnamed: R206.2, U201.8 (RXD0/MODE0)
unnamed: R207.2, U201.7 (RXD1/MODE1)
unnamed: R203.2, U201.10 (RXER/PHYAD0)
unnamed: R210.1, U201.5 (XTAL1/CLKIN)
unnamed: R205.2, U201.14 (~INT/REFCLKO)
unnamed: C202.2, R209.2, U201.15 (~RST)

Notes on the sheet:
10mA
LAN8720 Module

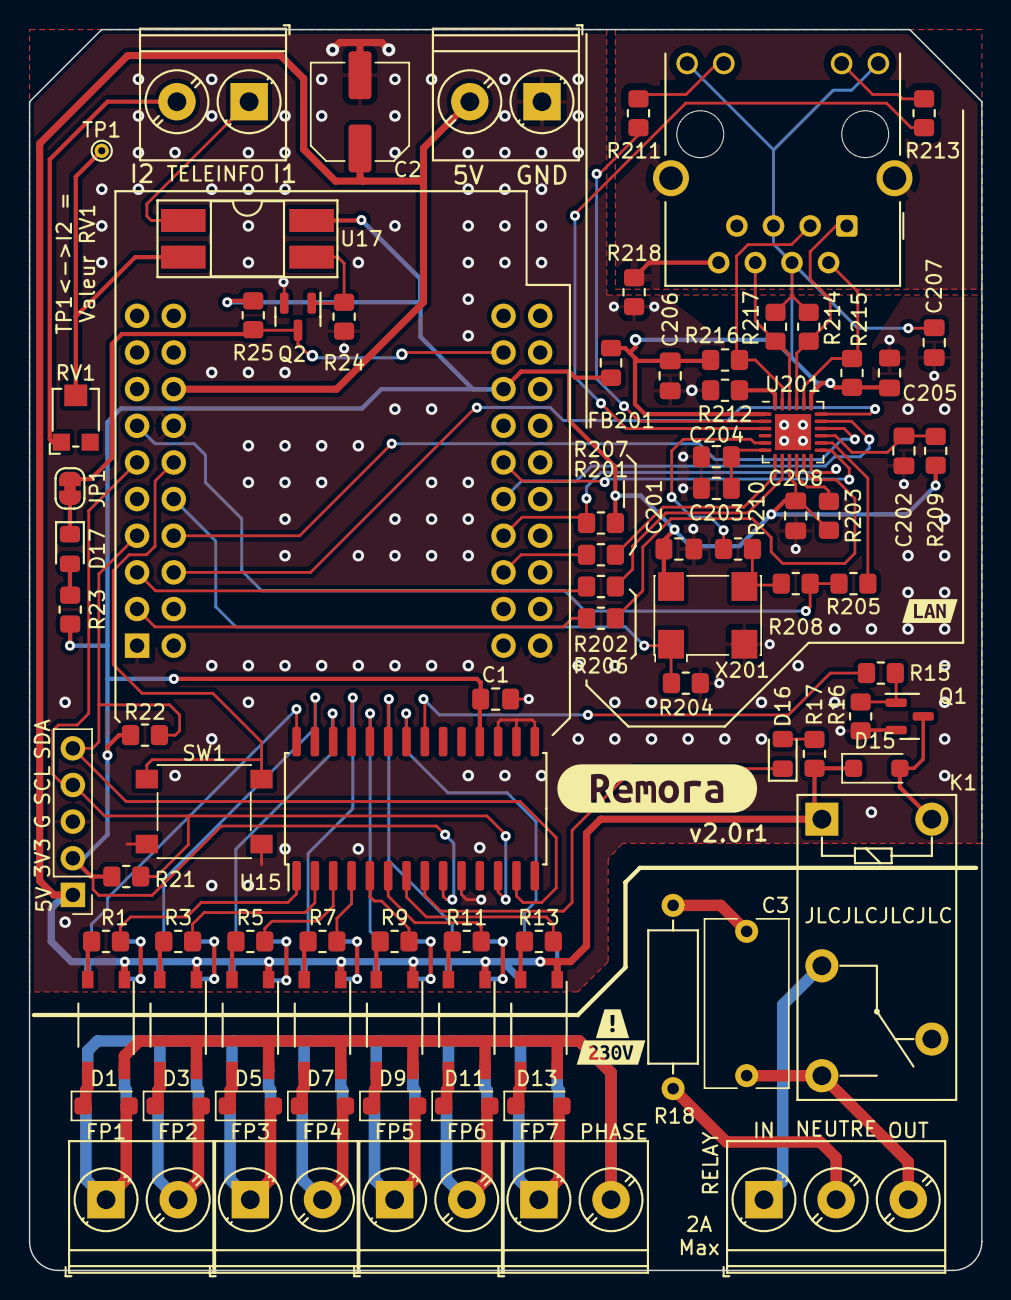
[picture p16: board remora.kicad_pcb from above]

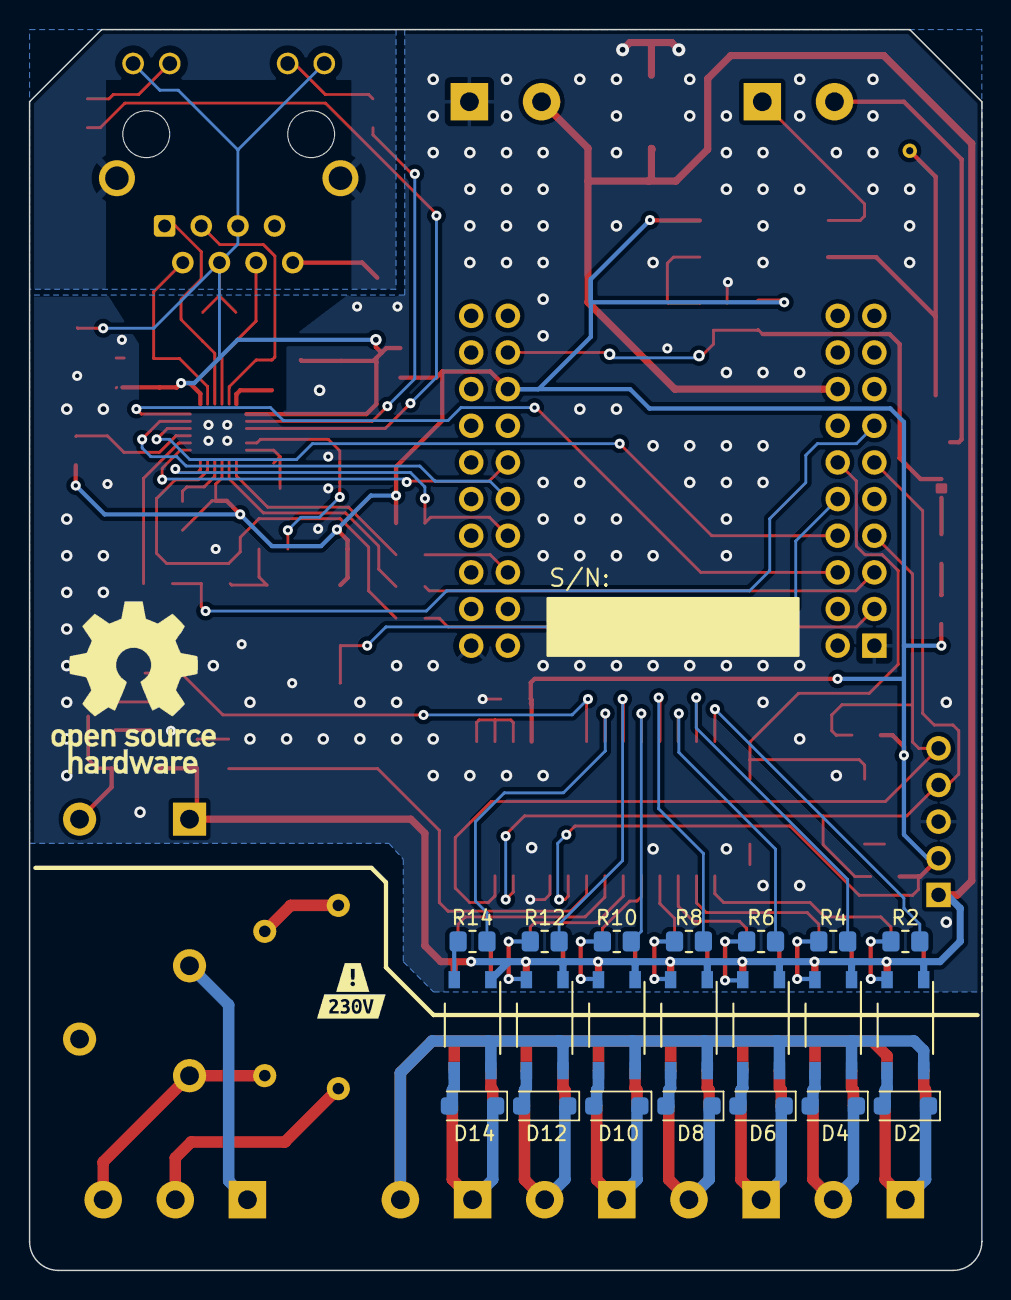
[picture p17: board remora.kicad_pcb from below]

Board: 2 copper layers, 66.0 x 86.0 mm, 111 parts (23 on the bottom side), 102 nets.

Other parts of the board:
kibuzzard-65A3E6CE, kibuzzard-65A3E6CE#2: G***; kibuzzard-65A3E6CE
kibuzzard-65A3E49B, kibuzzard-65A3E49B#2: G***; kibuzzard-65A3E49B
kibuzzard-659BD475: G***; kibuzzard-659BD475
kibuzzard-659BD659: G***; kibuzzard-659BD659

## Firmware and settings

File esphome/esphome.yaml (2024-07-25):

esphome:
  name: remora2
  friendly_name: remora2

esp32:
  board: esp32dev
  framework:
    type: arduino

# Enable logging
logger:

# Enable Home Assistant API
api:
  encryption:
    key: "xxxx"

  

wifi:
  ssid: !secret wifi_ssid
  password: !secret wifi_password

  # Enable fallback hotspot (captive portal) in case wifi connection fails
#  ap:
#    ssid: "Esphome-Remora"
#    password: "xxxx"

#  manual_ip:
#    static_ip: 192.168.0.238
#    gateway: 192.168.0.254
#    subnet: 255.255.255.0

# captive_portal:

# For LAN
#ethernet:
#  type: LAN8720
#  mdc_pin: GPIO23
#  mdio_pin: GPIO18
#  clk_mode: GPIO0_IN
#  power_pin: GPIO17
#  phy_addr: 1
#
#  manual_ip:
#    static_ip: 192.168.0.238
#    gateway: 192.168.0.254
#    subnet: 255.255.255.0

ota:
  platform: esphome


uart:
  - id: uart_1
    baud_rate: 9600
    rx_pin: GPIO13
    data_bits: 7
    parity: EVEN

teleinfo:
  - id: linky
    uart_id: uart_1
    update_interval: 10s


i2c:
  sda: 32
  scl: 4

mcp23017:
  - id: 'mcp23017_hub'
    address: 0x20

packages:
  fp1: !include
    file: common/fil-pilote.yaml
    vars:
      fp_num: 1
      a_pin: 8
      b_pin: 7

  fp2: !include
    file: common/fil-pilote.yaml
    vars:
      fp_num: 2
      a_pin: 9
      b_pin: 6

  fp3: !include
    file: common/fil-pilote.yaml
    vars:
      fp_num: 3
      a_pin: 10
      b_pin: 5

  fp4: !include
    file: common/fil-pilote.yaml
    vars:
      fp_num: 4
      a_pin: 11
      b_pin: 4

  fp5: !include
    file: common/fil-pilote.yaml
    vars:
      fp_num: 5
      a_pin: 12
      b_pin: 3

  fp6: !include
    file: common/fil-pilote.yaml
    vars:
      fp_num: 6
      a_pin: 13
      b_pin: 2

  fp7: !include
    file: common/fil-pilote.yaml
    vars:
      fp_num: 7
      a_pin: 14
      b_pin: 1

switch:
  #Relay
  - platform: gpio
    name: "Relai"
    pin:
      mcp23xxx: mcp23017_hub
      # Use pin A0
      number: 0
      mode:
        output: true
  #Relay LED
  - platform: gpio
    name: "LED relai"
    pin:
      mcp23xxx: mcp23017_hub
      # Use pin B7
      number: 15
      mode:
        output: true
      inverted: true

binary_sensor:
  - platform: gpio
    name: "Bouton"
    pin:
      number: 16
      inverted: true
      mode:
        input: true
        pullup: true


sensor:
  - platform: teleinfo
    teleinfo_id: linky
    tag_name: "SINSTS"
    name: sinsts
    unit_of_measurement: "VA"
    icon: mdi:flash

  - platform: teleinfo
    teleinfo_id: linky
    tag_name: "EASD01"
    name: conso_hc
    unit_of_measurement: "Wh"
    icon: mdi:flash

  - platform: teleinfo
    teleinfo_id: linky
    tag_name: "EASD02"
    name: conso_hp
    unit_of_measurement: "Wh"
    icon: mdi:flash
    #bug in teleinfo checksum for EASD02, we don't allow to send 0
    #https://github.com/esphome/issues/issues/4891#issuecomment-1902267482
    device_class: "energy"
    state_class: "total_increasing"
    filters:
     - lambda: |-
         float MAX_DIFFERENCE = 10000.0;
         static float last_value = NAN;
         if (isnan(last_value) || std::abs(x - last_value) < MAX_DIFFERENCE)
           return last_value = x;
         else
           return {};

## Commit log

2024-01-14 Ajout version 2.0
    [EVM3ESX50Bxx-Panasonic.STEP, HR911105A.STEP, QFN 24 4x4.step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]
2024-01-28 Add Switch
    [Tactal Switch - SMD (6mm x 6mm x 5mm).stp, remora.kicad_pcb, remora.kicad_sch]
2024-01-28 Modif commande v2.0
    [phy.kicad_sch, remora.kicad_pcb, remora.kicad_sch]
2024-02-25 Mise a jour resistance puissance LED
    [phy.kicad_sch, remora.kicad_sch]
2024-02-26 Mise a jour 1er assemblage
    [phy.kicad_sch, remora.kicad_pcb, remora.kicad_sch]
2024-03-02 Fix transistor relai (collecteur et émeteur intervertis)
    [remora.kicad_pcb, remora.kicad_sch]
2024-07-14 Deplacement du pin teleinfo de SD1 à GPIO13
    [phy.kicad_sch, remora.kicad_pcb, remora.kicad_sch]
2024-07-25 Ajout de la configuration ESPHome
2024-08-28 Nouvelles empreintes pour les diodes
    Les pads des diodes ont été agrandies et espacées pour respecter la datasheet.
    Changement ref des borniers pour du 2.5mm²
    [remora.kicad_pcb, remora.kicad_sch]
2024-08-28 Version 2.0 r1
    [remora.kicad_pcb]

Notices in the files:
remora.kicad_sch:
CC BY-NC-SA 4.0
